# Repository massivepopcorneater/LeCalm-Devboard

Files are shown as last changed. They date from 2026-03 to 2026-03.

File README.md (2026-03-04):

# LeCalm-Devboard
LeCalm Devboard is a open-source devboard built around the Raspberry Pi RP2040 microcontroller. It features a USB-C connector for programming and power, an onboard 3.3V regulator, a 16MB flash chip, and a 12MHz crystal oscillator for precise timing. The board includes a BOOTSEL button for firmware flashing.
This project was designed in KiCad as a personal learning project, exploring PCB layout, component selection, and design for manufacture with JLCPCB.

## Schematic
Schematic
The schematic of the LeCalm Devboard centers around the RP2040 microcontroller. The power section takes 5V from the USB-C connector and passes it through the MCP1700 LDO regulator to produce a clean 3.3V rail, with 1uF and 10uF bulk capacitors smoothing out any voltage fluctuations. Each power pin on the RP2040 is decoupled with a dedicated 0.1uF capacitor placed as close to the pin as possible to suppress high frequency noise. The 12MHz crystal oscillator is connected to the XIN and XOUT pins of the RP2040 with two 33pF load capacitors to ground, providing the precise clock reference needed for full speed operation and stable USB communication. The USB-C connector is wired with 5.1K resistors on the CC1 and CC2 configuration pins for proper power negotiation, and 27Ω series resistors on the D+ and D- differential pair to reduce signal reflections. The W25Q128JVS flash chip is connected to the RP2040 via SPI with all power pins properly decoupled, and the BOOTSEL button is wired to the flash chip select line through a current limiting resistor to ground, allowing the RP2040 to enter USB Mass Storage mode on boot when pressed.

## PCB Design
PCB Design

The PCB layout of the LeCalm Devboard was designed in KiCad with a focus on signal integrity and clean power distribution.  Decoupling capacitors are placed as close as physically possible to the power pins of the RP2040 and the W25Q128JVS flash chip to minimize trace inductance and ensure effective high frequency filtering. The 12MHz crystal oscillator is positioned close to the XIN and XOUT pins of the RP2040 to keep the clock traces short and reduce the risk of noise pickup. The USB-C connector is placed at the edge of the board for easy access, with the 27Ω series resistors on the D+ and D- differential pair routed as a matched length pair to maintain signal integrity across the USB data lines. A ground copper pour covers both the front and back copper layers, providing a low impedance return path for all signals and helping to dissipate heat across the board. Thermal relief spokes are used where pads connect to the ground pour to ensure reliable soldering during assembly. The BOOTSEL button is positioned on the top of the board for easy access during firmware flashing. All SMD components use 0402 and 0603 imperial footprints, keeping the overall board size compact while remaining manufacturable through JLCPCBs standard PCB assembly service.

## Bill of Materials
| Designation | Designation | JLCPCB Part # | Value | Footprint |
| ---|---|---|---|---|
| Capacitor | C1, C10 | C52923 | 1uF | C_0402_1005Metric |
| Capacitor | C2, C3, C4, C5, C6, C7, C8, C9, C11, C12, C17 | C1525 | 0.1uF | C_0402_1005Metric |
| Capacitor | C13, C14 | C19702 | 10uF | C_0603_1608Metric |
| Capacitor | C15, C16 | C1562 | 33pF | C_0402_1005Metric |
| USB_C Power | J1 | C165948 | USB_C_Receptacle_USB2.0_14P | USB_C_Receptacle_HRO_TYPE-C-31-M-12 |
| Resistor | R1, R2 | C25905 | 5.1K | R_0402_1005Metric |
| Resistor | R3, R4 | C25100 | 27Ω | R_0402_1005Metric |
| Resistor | R5, R6 | C11702 | 1K | R_0402_1005Metric |
| Resistor | R7 | C25744 | 10K | R_0402_1005Metric |
| Bootsel Button | SW1 | C720477 | SW_Push | SW_Push_SPST_NO_Alps_SKRK |
| Microcontroller | U1 | C2040| RP2040 | QFN-56-1EP_7x7mm_P0.4mm_EP3.2x3.2mm |
| LDO | U2 | C39051 | MCP1700x-120xxTT | SOT-23 |
| Flash Memory | U3 | C2843335 | W25Q128JVS | Winbond_USON-8-1EP_3x2mm_P0.5mm_EP0.2x1.6mm |
| Crystal Oscillator | Y1 | C9002 | 12MHz | Crystal_SMD_Abracon_ABM8-2Pin_3.2x1.5mm |

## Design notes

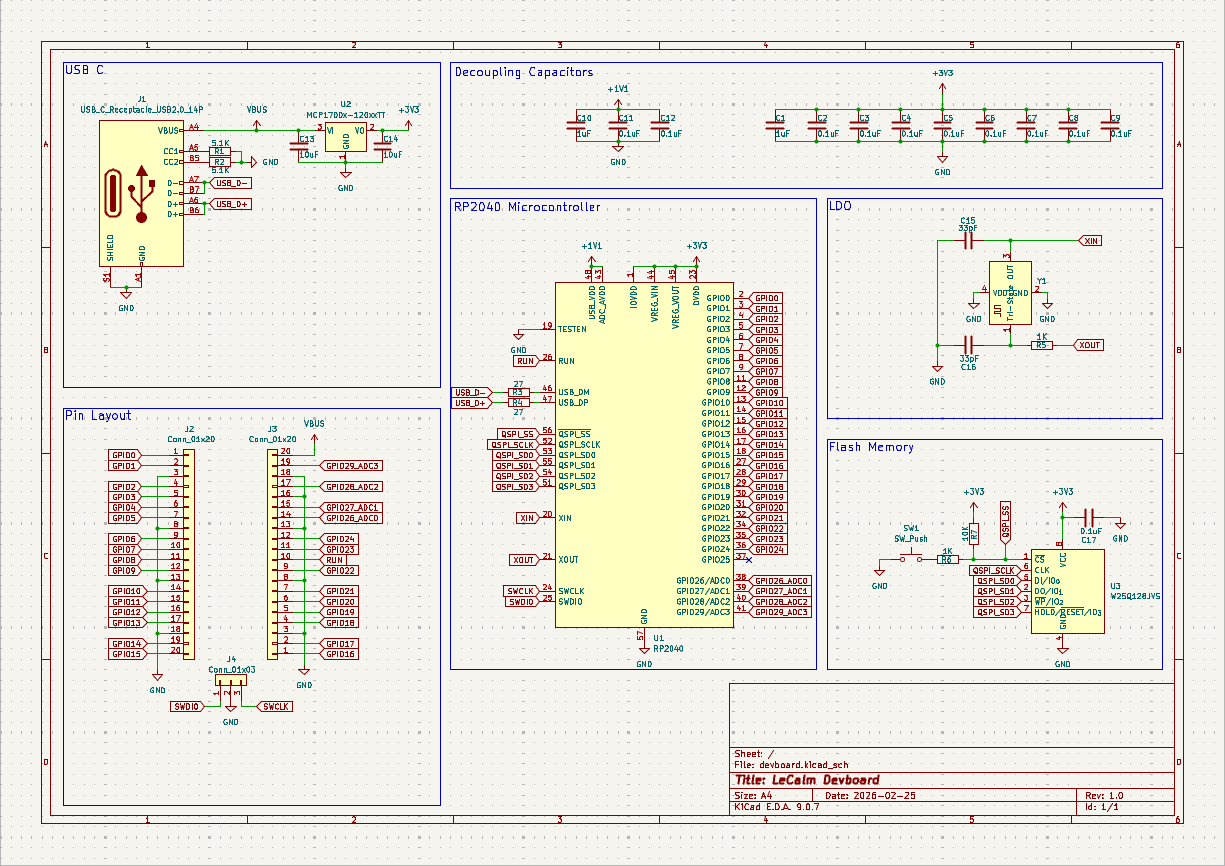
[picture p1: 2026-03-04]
Pictures/Schematic.png

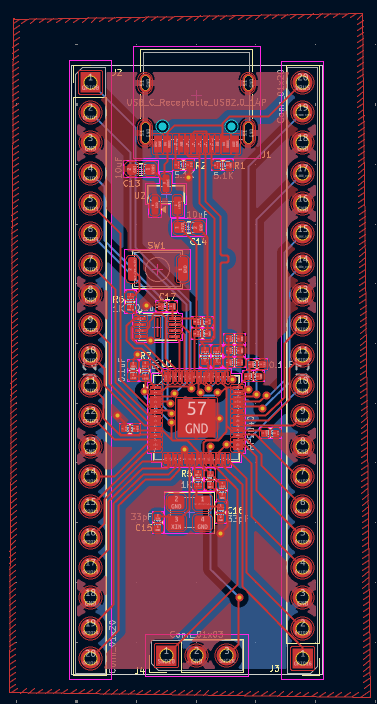
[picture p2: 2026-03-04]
Pictures/PCB Design.png

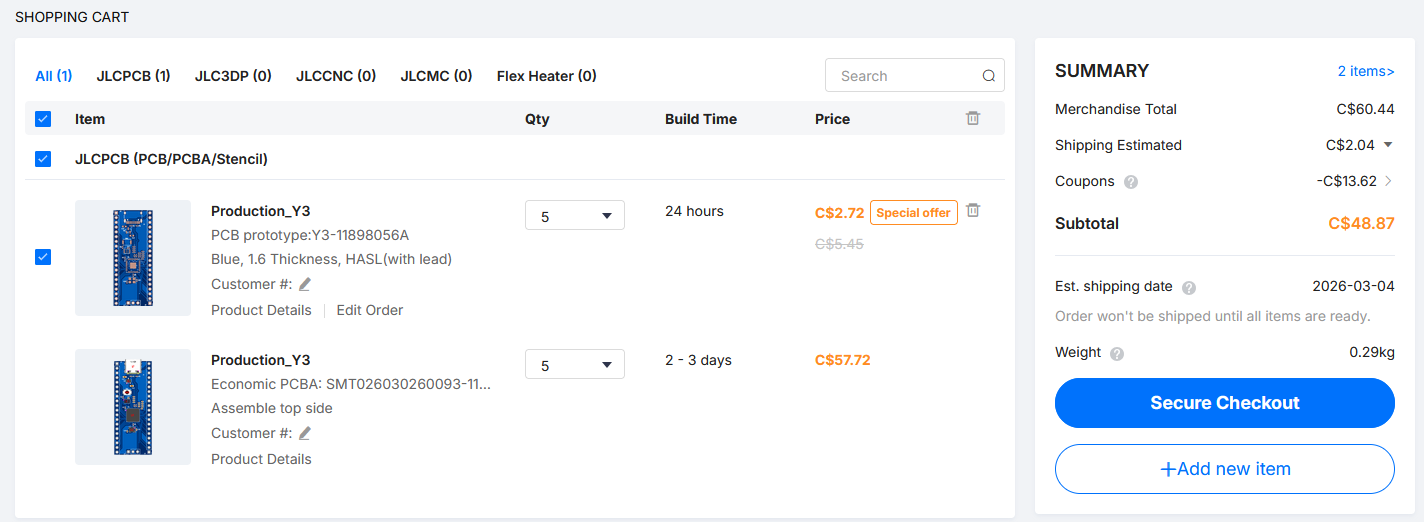
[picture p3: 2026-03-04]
Pictures/JLC_Cart.png

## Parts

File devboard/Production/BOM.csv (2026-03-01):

Id | Designator | Footprint | Quantity | Comment | Supplier and ref
1 | C14,C13 | C_0603_1608Metric | 2 | 10uF
2 | C1,C10 | C_0402_1005Metric | 2 | 1uF
3 | C2,C3,C4,C5,C6,C7,C8,C9,C11,C12,C17 | C_0402_1005Metric | 11 | 0.1uF
4 | C15,C16 | C_0402_1005Metric | 2 | 33pF
5 | J1 | USB_C_Receptacle_HRO_TYPE-C-31-M-12 | 1 | USB_C_Receptacle_USB2.0_14P
6 | J2,J3 | PinHeader_1x20_P2.54mm_Vertical | 2 | Conn_01x20
7 | J4 | PinHeader_1x03_P2.54mm_Vertical | 1 | Conn_01x03
8 | R1,R2 | R_0402_1005Metric | 2 | 5.1K
9 | R3,R4 | R_0402_1005Metric | 2 | 27
10 | R5,R6 | R_0402_1005Metric | 2 | 1K
11 | R7 | R_0402_1005Metric | 1 | 10K
12 | SW1 | SW_Push_SPST_NO_Alps_SKRK | 1 | SW_Push
13 | U1 | QFN-56-1EP_7x7mm_P0.4mm_EP3.2x3.2mm | 1 | RP2040
14 | U2 | SOT-23 | 1 | MCP1700x-120xxTT
15 | U3 | Winbond_USON-8-1EP_3x2mm_P0.5mm_EP0.2x1.6mm | 1 | W25Q128JVS
16 | Y1 | Crystal_SMD_3225-4Pin_3.2x2.5mm | 1 | 12MHz

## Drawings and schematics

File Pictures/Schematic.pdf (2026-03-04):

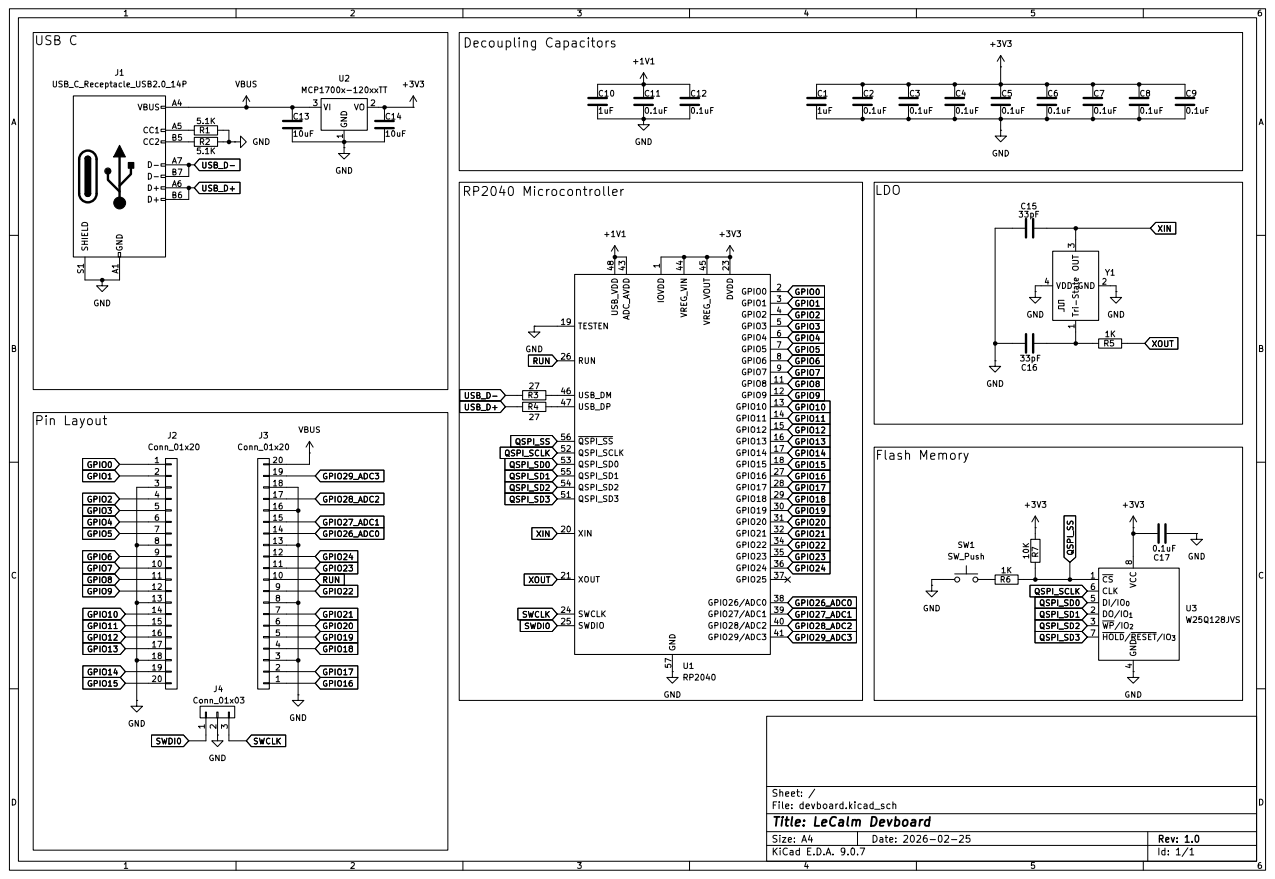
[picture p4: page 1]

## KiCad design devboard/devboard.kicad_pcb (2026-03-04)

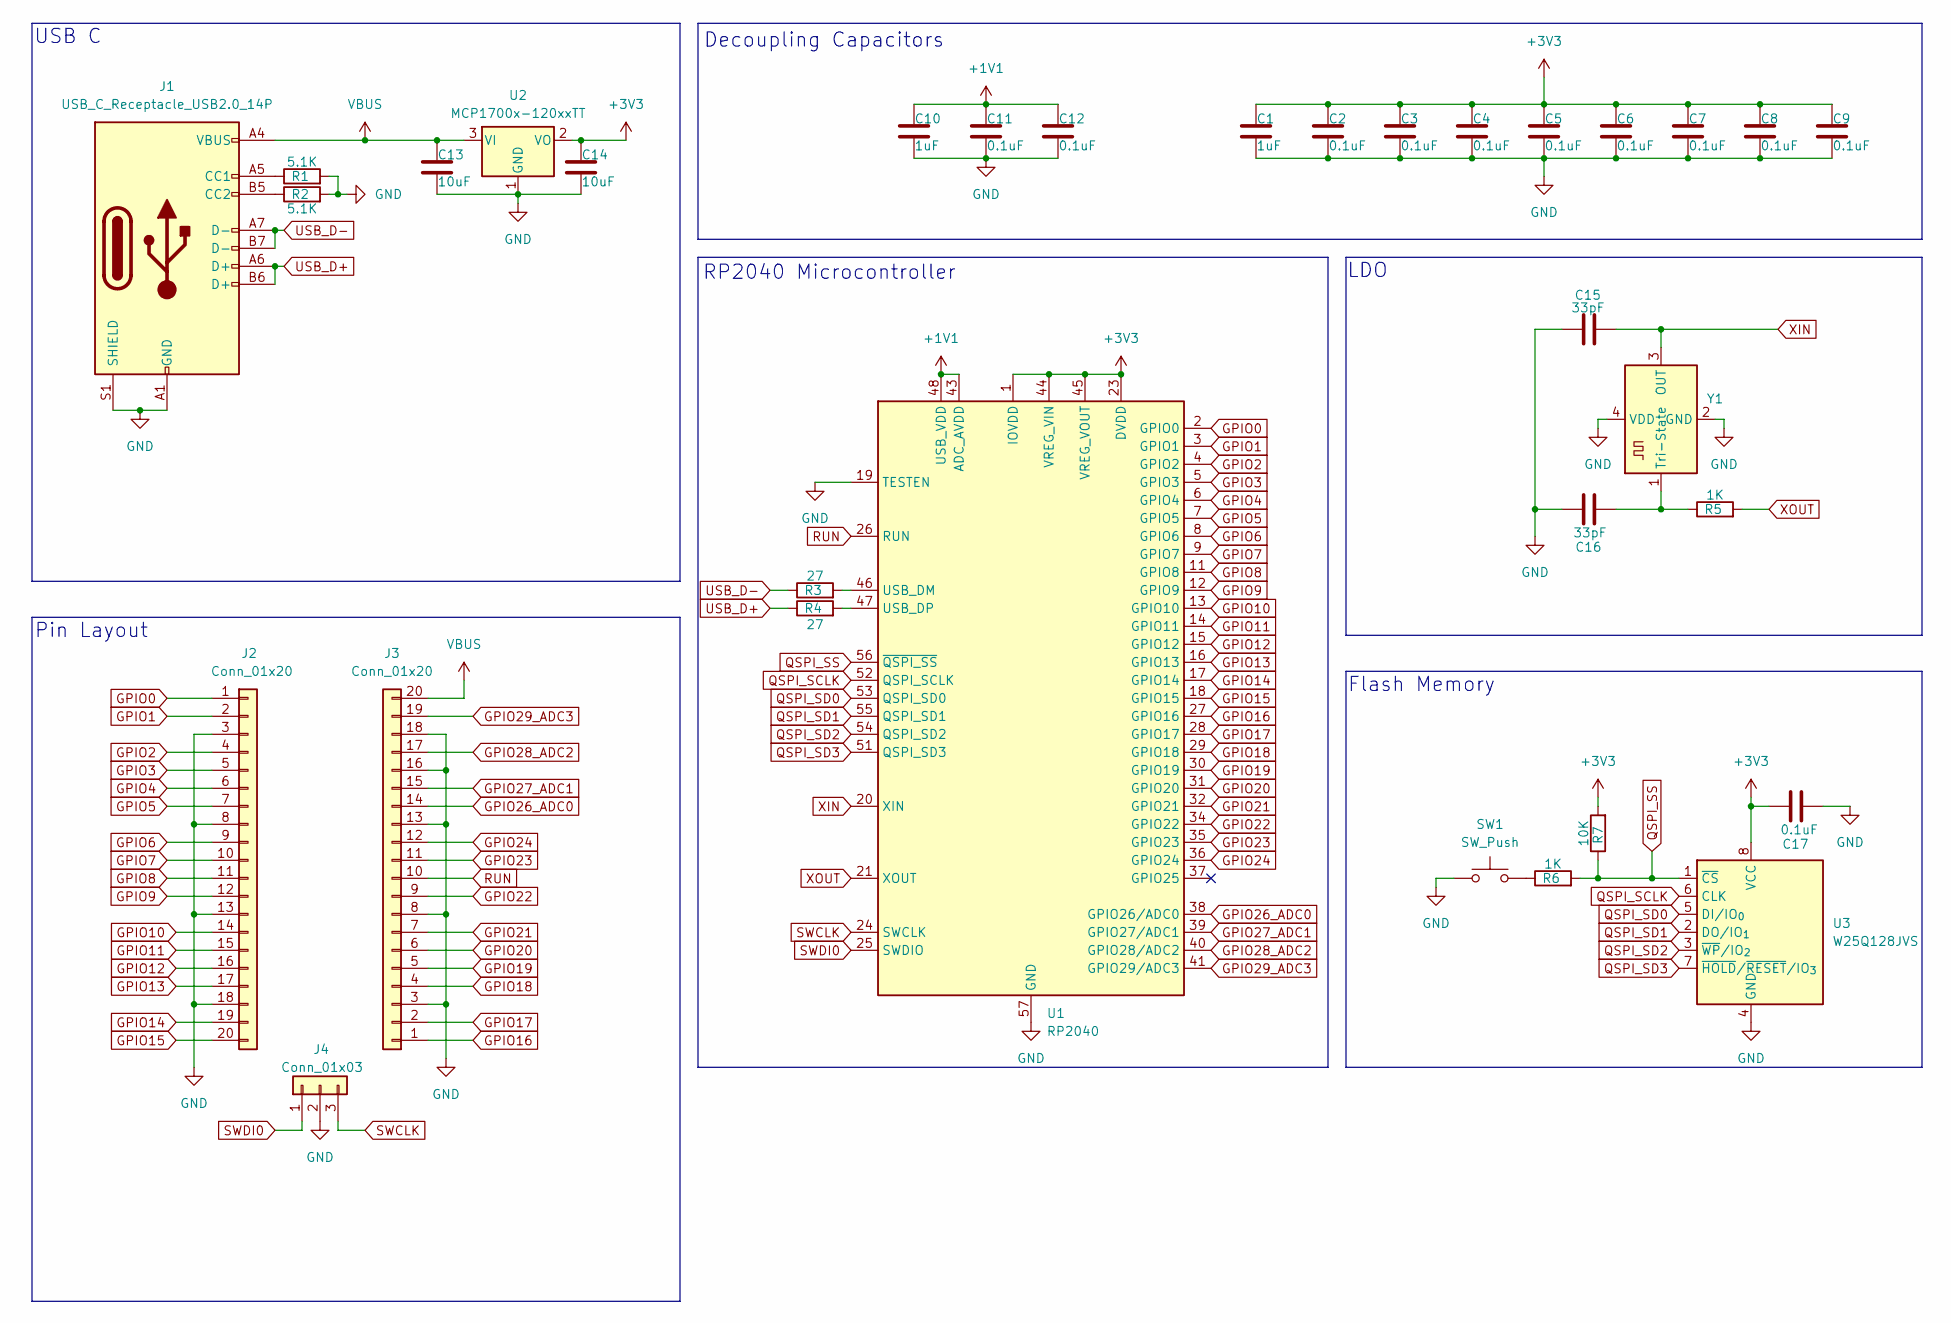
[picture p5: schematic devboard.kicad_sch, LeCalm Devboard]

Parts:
C1, C10: 1uF; C_0402_1005Metric
C2, C3, C4, C5, C6, C7, C8, C9, C11, C12, C17: 0.1uF; C_0402_1005Metric
C13, C14: 10uF; C_0603_1608Metric
C15, C16: 33pF; C_0402_1005Metric
J1: USB_C_Receptacle_USB2.0_14P; USB_C_Receptacle_HRO_TYPE-C-31-M-12
J2, J3: Conn_01x20; PinHeader_1x20_P2.54mm_Vertical
J4: Conn_01x03; PinHeader_1x03_P2.54mm_Vertical
R1, R2: 5.1K; R_0402_1005Metric
R3, R4: 27; R_0402_1005Metric
R5, R6: 1K; R_0402_1005Metric
R7: 10K; R_0402_1005Metric
SW1: SW_Push; SW_Push_SPST_NO_Alps_SKRK
U1: RP2040; QFN-56-1EP_7x7mm_P0.4mm_EP3.2x3.2mm
U2: MCP1700x-120xxTT; SOT-23
U3: W25Q128JVS; Winbond_USON-8-1EP_3x2mm_P0.5mm_EP0.2x1.6mm
Y1: 12MHz; Crystal_SMD_3225-4Pin_3.2x2.5mm

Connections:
+1V1: C10.1, C11.1, C12.1, U1.43 (ADC_AVDD), U1.48 (USB_VDD)
+3V3: C1.1, C2.1, C3.1, C4.1, C5.1, C6.1, C7.1, C8.1, C9.1, C14.1, C17.2, R7.2, U1.1 (IOVDD), U1.10 (IOVDD), U1.22 (IOVDD), U1.23 (DVDD), U1.33 (IOVDD), U1.42 (IOVDD), U1.44 (VREG_VIN), U1.45 (VREG_VOUT), U1.49 (IOVDD), U1.50 (DVDD), U2.2 (VO), U3.8 (VCC)
GND: C1.2, C2.2, C3.2, C4.2, C5.2, C6.2, C7.2, C8.2, C9.2, C10.2, C11.2, C12.2, C13.2, C14.2, C15.1, C16.2, C17.1, J1.A1 (GND), J1.A12 (GND), J1.B1 (GND), J1.B12 (GND), J1.S1 (SHIELD), J2.3, J2.8, J2.13, J2.18, J3.3, J3.8, J3.13, J3.16, J3.18, J4.2, R1.2, R2.2, SW1.1, U1.19 (TESTEN), U1.57 (GND), U2.1 (GND), U3.4 (GND), Y1.2 (GND), Y1.4 (VDD)
GPIO0: J2.1, U1.2 (GPIO0)
GPIO1: J2.2, U1.3 (GPIO1)
GPIO2: J2.4, U1.4 (GPIO2)
GPIO3: J2.5, U1.5 (GPIO3)
GPIO4: J2.6, U1.6 (GPIO4)
GPIO5: J2.7, U1.7 (GPIO5)
GPIO6: J2.9, U1.8 (GPIO6)
GPIO7: J2.10, U1.9 (GPIO7)
GPIO8: J2.11, U1.11 (GPIO8)
GPIO9: J2.12, U1.12 (GPIO9)
GPIO10: J2.14, U1.13 (GPIO10)
GPIO11: J2.15, U1.14 (GPIO11)
GPIO12: J2.16, U1.15 (GPIO12)
GPIO13: J2.17, U1.16 (GPIO13)
GPIO14: J2.19, U1.17 (GPIO14)
GPIO15: J2.20, U1.18 (GPIO15)
GPIO16: J3.1, U1.27 (GPIO16)
GPIO17: J3.2, U1.28 (GPIO17)
GPIO18: J3.4, U1.29 (GPIO18)
GPIO19: J3.5, U1.30 (GPIO19)
GPIO20: J3.6, U1.31 (GPIO20)
GPIO21: J3.7, U1.32 (GPIO21)
GPIO22: J3.9, U1.34 (GPIO22)
GPIO23: J3.11, U1.35 (GPIO23)
GPIO24: J3.12, U1.36 (GPIO24)
GPIO26_ADC0: J3.14, U1.38 (GPIO26/ADC0)
GPIO27_ADC1: J3.15, U1.39 (GPIO27/ADC1)
GPIO28_ADC2: J3.17, U1.40 (GPIO28/ADC2)
GPIO29_ADC3: J3.19, U1.41 (GPIO29/ADC3)
unnamed: J1.A5 (CC1), R1.1
unnamed: J1.B5 (CC2), R2.1
unnamed: R6.1, SW1.2
unnamed: R3.2, U1.46 (USB_DM)
unnamed: R4.2, U1.47 (USB_DP)
unnamed: C16.1, R5.1, Y1.1 (Tri-State)
QSPI_SCLK: U1.52 (QSPI_SCLK), U3.6 (CLK)
QSPI_SD0: U1.53 (QSPI_SD0), U3.5 (DI/IO_{0})
QSPI_SD1: U1.55 (QSPI_SD1), U3.2 (DO/IO_{1})
QSPI_SD2: U1.54 (QSPI_SD2), U3.3 (~WP/IO_{2})
QSPI_SD3: U1.51 (QSPI_SD3), U3.7 (~HOLD/~RESET/IO_{3})
QSPI_SS: R6.2, R7.1, U1.56 (~QSPI_SS), U3.1 (~CS)
RUN: J3.10, U1.26 (RUN)
SWCLK: J4.3, U1.24 (SWCLK)
SWDI0: J4.1, U1.25 (SWDIO)
USB_D+: J1.A6 (D+), J1.B6 (D+), R4.1
USB_D-: J1.A7 (D-), J1.B7 (D-), R3.1
VBUS: C13.1, J1.A4 (VBUS), J1.A9 (VBUS), J1.B4 (VBUS), J1.B9 (VBUS), J3.20, U2.3 (VI)
XIN: C15.2, U1.20 (XIN), Y1.3 (OUT)
XOUT: R5.2, U1.21 (XOUT)

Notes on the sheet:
USB C
Flash Memory
Pin Layout
LDO
Decoupling Capacitors
RP2040 Microcontroller

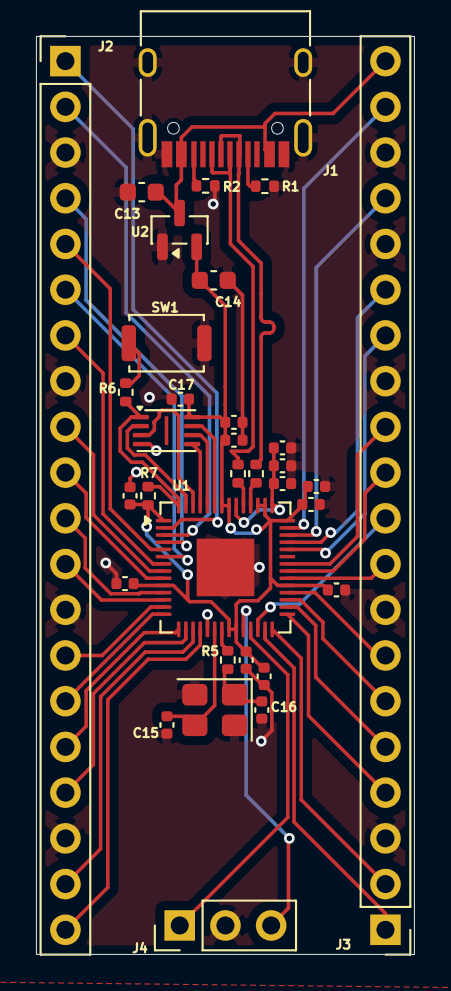
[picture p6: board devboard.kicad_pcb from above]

Board: 2 copper layers, 21.0 x 51.0 mm, 33 parts (0 on the bottom side), 52 nets.

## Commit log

2026-02-10 file creation
    [devboard.kicad_pcb, devboard.kicad_sch]
2026-02-25 Finished basic schematic of Devboard 1.0
    The schematics of the devboard with basic functionalities was finished.
    [devboard.kicad_sch]
2026-03-01 PCB Starter
    [devboard.kicad_pcb]
2026-03-01 PCB routing and changes
    [devboard.kicad_pcb, devboard.kicad_sch]
2026-03-01 Production file generation + final pcb update
    [BOM.csv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]
2026-03-04 final fr
    [devboard-B_Cu.gbr, devboard-B_Mask.gbr, devboard-B_Paste.gbr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]
